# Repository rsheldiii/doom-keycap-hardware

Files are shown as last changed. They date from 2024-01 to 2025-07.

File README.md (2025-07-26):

# Doom Keycap Hardware Repository



Here are all the files associated with the hardware for the Doom Keycap. If you're looking for the code, it's [here](https://github.com/rsheldiii/rp2040-doom-LCD/).

I had every intention of fabricating and selling these myself, but I got caught up on how to manufacture the keycap itself without A. breaking the bank, or B. doing a group buy before realizing my design wasn't feasible. With that, coupled with (happy) life events, I decided to open-source the hardware now.

## Doom Business Card

I handed out quite a few of these during OpenSauce 2025! You can check the subfolder for the front paste file (which you can use to generate a highly-recommended stencil at osh stencils) and the BOM. Happy soldering and good luck!

## Doom Keycap Kicad

This directory houses the Kicad files for the final version of the Doom Keycap PCB. It was essentially a mashup of the RP2040 minimal pcb and Adafruit's schematic for the [MAX98357AETE breakout board](https://learn.adafruit.com/adafruit-max98357-i2s-class-d-mono-amp/downloads), with a semi-standard FPC connector for SPI displays and smaller parts. Quick facts:

* The footprint library did not make the jump to a new operating system, but the footprints are embedded in the PCB file; you can right-click "edit footprint", save-as, and then reassociate them in the schematic. Or you know, you could not.
* I used screens from [this](https://www.aliexpress.us/item/3256803794221438.html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) aliexpress listing, which have FPC connectors that look like [this](https://imgur.com/btXJBdo). No other FPC connector will work on this iteration of the board (obviously)
* Finding a small but powerful enough speaker was a challenge. The small screen versions of the keycap did not have a speaker installed due to size constraints.
* I calculated the value of the crystal oscillator's capacitors wrong; it starts up, but it requires an extra flag during program compilation to give the crystal more time to stabilize. It should work as-is, but optimizing those values would be ideal
* The hardware design / components selected might not be well-optimized, I'm a computer scientist by trade. I did my best though.
* The flash memory could definitely be smaller, but beware: not all memory chips are drop-in replacements. Similarly, the voltage regulator could have a much smaller footprint, I just couldn't find one at the time. If you do swap the regulator and you want to play doom on the keycap with a keyboard, remember the regulator will be supplying electricity to the keyboard, not the other way around. 

## Doom Keycap Case

Here are the final couple STLs I generated for the model, plus the fusion 360 file I used to generate them. 

* the f3d file should have comments in the parameters section about the size of the larger screen, if you wish to make the large version of the keycap.
* If you want to install a speaker on the small version, you'll need to increase the space available to the PCB
* These parts were printed on a resin printer in transparent resin, processed, and then hit with clear gloss lacquer. My plan was to switch to an acrylic insert for mass production.

## Fabrication tips

* Unless you are a god-tier solderer, you're not going to get away with hand-soldering these boards; you will need a stencil and a reflow oven or similar. OSHPark has a sister-service for cheap stencils, which is what I used.
* You _can_ get away with a single stencil for the top of the board and hand-soldering the bottom though. the only tricky part is the FPC connector, but with extra flux and dragging the tip, the solder should wick where it needs to go. 
* The LED on the board is keyed to blink at certain critical moments in the program; if you aren't getting _any_ blinking at all, it means the device is malfunctioning. If you get _some_ blinking that stops, you probably forgot to burn the wad file to memory - I can't tell you how many times I did this. A screen does not have to be installed for the program to run successfully.
* if you upload a program that runs fine, but is then forgotten, you need to set PICO_XOSC_STARTUP_DELAY_MULTIPLIER. The crystal isn't stabilizing fast enough, which is causing the RP2040 to give up on reading the flash chip
* Fitment on the case is very tight; try not to over-bend the FPC on the screen
* Power can be delivered through the USB connector, or through the pads on the bottom of the PCB (refer to schematic for polarity). The voltage regulator in the BOM has more than enough power to run a simple keyboard, though I would be careful with LED keyboards. 1S lipos should work as well. If you want to use another power source, there are very many voltage regulators in the SOT223 package

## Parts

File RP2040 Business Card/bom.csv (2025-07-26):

Designator | Footprint | Quantity | Value | LCSC Part # | MFR Part #
C1, C17, C4, C9 | 402 | 4 | 10u | C15525 | CL05A106MQ5NUNC
C10, C8 | 402 | 2 | 1u | C52923 | CL05A105KA5NQNC
C11, C14, C15, C16, C18, C19, C20, C21, C5, C6, C7 | 402 | 11 | 100n | C1525 | CL05B104KO5NNNC
C12, C13 | 402 | 2 | 220p | C1530 | 0402B221K500NT
C2, C3 | 402 | 2 | 27p | C1557 | 0402CG270J500NT
D1 | 603 | 1 | LED | C2290 | KT-0603W
D2, D3 | 805 | 2 | D_Schottky
J1 | GCT_USB4105-GF-A | 1 | USB_C_Receptacle_USB2.0 | C3020560 | USB4105-GF-A
J2 | PinSocket_1x16_P2.54mm_Vertical | 1 | Conn_01x16_Socket
J6 | USB_C_Receptacle_GCT_USB4135-GF-A_6P_TopMnt_Horizontal | 1 | USB_C_Receptacle_PowerOnly_6P | C5438410 | USB4135-GF-A
LS1 | CMS_131304_smt_tr | 1 | Speaker | C9900205221 | CMS-131304-SMT-TR
R1, R5, R8 | 402 | 3 | 1k | C11702 | 0402WGF1001TCE
R10, R11 | 402 | 2 | 5.1k | C25905 | 0402WGF5101TCE
R12, R2 | 402 | 2 | DNF
R13, R9 | 402 | 2 | 56k | C25796 | 0402WGF5602TCE
R3, R4 | 402 | 2 | 27 | C138021 | RC0402FR-0727RL
R6 | 402 | 1 | 100k | C25741 | 0402WGF1003TCE
R7 | 402 | 1 | 680k | C163456 | RC0402FR-07680KL
SW1 | PTS636_SL50_SMTR_LFS Tactile Switch | 1 | Conn_01x02 | C2801322 | PTS636 SL50 SMTR LFS
U1 | SOT-223-3_TabPin2 | 1 | NCP1117-3.3_SOT223 | C26537 | NCP1117ST33T3G
U2 | SOIC-8_5.23x5.23mm_P1.27mm | 1 | W25Q128JVS | C97521 | W25Q128JVSIQ
U3 | RP2040-QFN-56 | 1 | RP2040 | C2040 | RP2040
U4 | 2328702-8 | 1 |  | C3168593 | 2328702-8
U5 | MAX98357AETE-T | 1 | MAX98357AETE+T | C910544 | MAX98357AETE+T
Y1 | 403C35D12M00000 | 1 | ABLS-12.000MHZ-B4-T | C1985831 | 403C35D12M00000

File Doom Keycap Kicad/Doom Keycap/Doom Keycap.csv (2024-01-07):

Source: | C:\Users\Dday\Documents\Documents\Projects\Doom Keycap\Doom Keycap Kicad\Doom Keycap\Doom Keycap.kicad_sch
Date: | 5/19/2023 12:42:28 PM
Tool: | Eeschema (6.0.9)
Generator: | C:\Program Files\KiCad\6.0\bin\scripting\plugins/bom_csv_grouped_by_value.py
Component Count: | 41
Individual Components:
Item | Qty | Reference(s) | Value | LibPart | Footprint | Datasheet
 |  | C1 | 10u | Device:C | Capacitor_SMD:C_0402_1005Metric | ~
 |  | C2 | 27p | Device:C | Capacitor_SMD:C_0402_1005Metric | ~
 |  | C3 | 27p | Device:C | Capacitor_SMD:C_0402_1005Metric | ~
 |  | C4 | 10u | Device:C | Capacitor_SMD:C_0402_1005Metric | ~
 |  | C5 | 100n | Device:C | Capacitor_SMD:C_0402_1005Metric | ~
 |  | C6 | 100n | Device:C | Capacitor_SMD:C_0402_1005Metric | ~
 |  | C7 | 100n | Device:C | Capacitor_SMD:C_0402_1005Metric | ~
 |  | C8 | 1u | Device:C | Capacitor_SMD:C_0402_1005Metric | ~
 |  | C9 | 10u | Device:C | Capacitor_SMD:C_0402_1005Metric | ~
 |  | C10 | 1u | Device:C | Capacitor_SMD:C_0402_1005Metric | ~
 |  | C11 | 100n | Device:C | Capacitor_SMD:C_0402_1005Metric | ~
 |  | C12 | 220p | Device:C | Capacitor_SMD:C_0402_1005Metric | ~
 |  | C13 | 220p | Device:C | Capacitor_SMD:C_0402_1005Metric | ~
 |  | C17 | 10u | Device:C | Capacitor_SMD:C_0402_1005Metric | ~
 |  | D1 | LED | Device:LED | LED_SMD:LED_0603_1608Metric | ~
 |  | D2 | D_Schottky | Device:D_Schottky | Diode_SMD:D_0402_1005Metric | ~
 |  | FID1 | Fiducial | Mechanical:Fiducial | Fiducial:Fiducial_0.5mm_Mask1mm | ~
 |  | FID2 | Fiducial | Mechanical:Fiducial | Fiducial:Fiducial_0.5mm_Mask1mm | ~
 |  | FID3 | Fiducial | Mechanical:Fiducial | Fiducial:Fiducial_0.5mm_Mask1mm | ~
 |  | FID4 | Fiducial | Mechanical:Fiducial | Fiducial:Fiducial_0.5mm_Mask1mm | ~
 |  | FID5 | Fiducial | Mechanical:Fiducial | Fiducial:Fiducial_0.5mm_Mask1mm | ~
 |  | FID6 | Fiducial | Mechanical:Fiducial | Fiducial:Fiducial_0.5mm_Mask1mm | ~
 |  | J1 | USB_B_Micro | Doom-Keycap-rescue:USB_B_Micro-Connector | RP2040_minimal:USB_Micro-B_Amphenol_10103594-0001LF_Horizontal_modified
 |  | J2 | Conn_01x02 | Jumper:SolderJumper_2_Open | Jumper:SolderJumper-2_P1.3mm_Open_Pad1.0x1.5mm | ~
 |  | J3 | Conn_01x01_Female | Connector:Conn_01x01_Female | TestPoint:TestPoint_Pad_D1.0mm | ~
 |  | J4 | Conn_01x01_Female | Connector:Conn_01x01_Female | TestPoint:TestPoint_Pad_D1.0mm | ~
 |  | LS1 | Speaker | Device:Speaker | Custom:SMS-1308MS-2-R | ~
 |  | R1 | 1k | Device:R | Resistor_SMD:R_0402_1005Metric | ~
 |  | R2 | DNF | Device:R | Resistor_SMD:R_0402_1005Metric | ~
 |  | R3 | 27 | Device:R | Resistor_SMD:R_0402_1005Metric | ~
 |  | R4 | 27 | Device:R | Resistor_SMD:R_0402_1005Metric | ~
 |  | R5 | 1k | Device:R | Resistor_SMD:R_0402_1005Metric | ~
 |  | R6 | 100k | Device:R | Resistor_SMD:R_0402_1005Metric | ~
 |  | R7 | 680k | Device:R | Resistor_SMD:R_0402_1005Metric | ~
 |  | R8 | 1K | Device:R | Resistor_SMD:R_0402_1005Metric | ~
 |  | U1 | NCP1117-3.3_SOT223 | Regulator_Linear:NCP1117-3.3_SOT223 | Package_TO_SOT_SMD:SOT-223-3_TabPin2 | http://www.onsemi.com/pub_link/Collateral/NCP1117-D.PDF
 |  | U2 | W25Q128JVS | Memory_Flash:W25Q128JVS | Package_SO:SOIC-8_5.23x5.23mm_P1.27mm | http://www.winbond.com/resource-files/w25q128jv_dtr%20revc%2003272018%20plus.pdf
 |  | U3 | RP2040 | MCU_RaspberryPi_RP2040:RP2040 | RP2040_minimal:RP2040-QFN-56
 |  | U4 | ST7735s_8 | Custom:ST7735s_8 | Custom:2328702-8
 |  | U5 | MAX98357AETE+T | Amp:MAX98357AETE+T | Custom:MAX98357AETE-T
 |  | Y1 | ABLS-12.000MHZ-B4-T | Device:Crystal | Custom:403C35D12M00000 | ~
Collated Components:
Item | Qty | Reference(s) | Value | LibPart | Footprint | Datasheet
1 | 4 | C1, C4, C9, C17 | 10u | Device:C | Capacitor_SMD:C_0402_1005Metric | ~
2 | 2 | C2, C3 | 27p | Device:C | Capacitor_SMD:C_0402_1005Metric | ~
3 | 4 | C5, C6, C7, C11 | 100n | Device:C | Capacitor_SMD:C_0402_1005Metric | ~
4 | 2 | C8, C10 | 1u | Device:C | Capacitor_SMD:C_0402_1005Metric | ~
5 | 2 | C12, C13 | 220p | Device:C | Capacitor_SMD:C_0402_1005Metric | ~
6 | 1 | D1 | LED | Device:LED | LED_SMD:LED_0603_1608Metric | ~
7 | 1 | D2 | D_Schottky | Device:D_Schottky | Diode_SMD:D_0402_1005Metric | ~
8 | 6 | FID1, FID2, FID3, FID4, FID5, FID6 | Fiducial | Mechanical:Fiducial | Fiducial:Fiducial_0.5mm_Mask1mm | ~
9 | 1 | J1 | USB_B_Micro | Doom-Keycap-rescue:USB_B_Micro-Connector | RP2040_minimal:USB_Micro-B_Amphenol_10103594-0001LF_Horizontal_modified
10 | 1 | J2 | Conn_01x02 | Jumper:SolderJumper_2_Open | Jumper:SolderJumper-2_P1.3mm_Open_Pad1.0x1.5mm | ~
11 | 2 | J3, J4 | Conn_01x01_Female | Connector:Conn_01x01_Female | TestPoint:TestPoint_Pad_D1.0mm | ~
12 | 1 | LS1 | Speaker | Device:Speaker | Custom:SMS-1308MS-2-R | ~
13 | 2 | R1, R5 | 1k | Device:R | Resistor_SMD:R_0402_1005Metric | ~
14 | 1 | R2 | DNF | Device:R | Resistor_SMD:R_0402_1005Metric | ~
15 | 2 | R3, R4 | 27 | Device:R | Resistor_SMD:R_0402_1005Metric | ~
16 | 1 | R6 | 100k | Device:R | Resistor_SMD:R_0402_1005Metric | ~
17 | 1 | R7 | 680k | Device:R | Resistor_SMD:R_0402_1005Metric | ~
18 | 1 | R8 | 1K | Device:R | Resistor_SMD:R_0402_1005Metric | ~
19 | 1 | U1 | NCP1117-3.3_SOT223 | Regulator_Linear:NCP1117-3.3_SOT223 | Package_TO_SOT_SMD:SOT-223-3_TabPin2 | http://www.onsemi.com/pub_link/Collateral/NCP1117-D.PDF
20 | 1 | U2 | W25Q128JVS | Memory_Flash:W25Q128JVS | Package_SO:SOIC-8_5.23x5.23mm_P1.27mm | http://www.winbond.com/resource-files/w25q128jv_dtr%20revc%2003272018%20plus.pdf
21 | 1 | U3 | RP2040 | MCU_RaspberryPi_RP2040:RP2040 | RP2040_minimal:RP2040-QFN-56
22 | 1 | U4 | ST7735s_8 | Custom:ST7735s_8 | Custom:2328702-8
23 | 1 | U5 | MAX98357AETE+T | Amp:MAX98357AETE+T | Custom:MAX98357AETE-T
24 | 1 | Y1 | ABLS-12.000MHZ-B4-T | Device:Crystal | Custom:403C35D12M00000 | ~

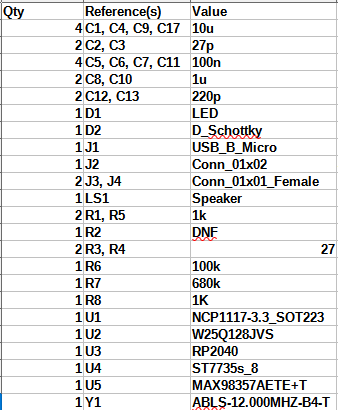
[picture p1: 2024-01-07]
bom.png

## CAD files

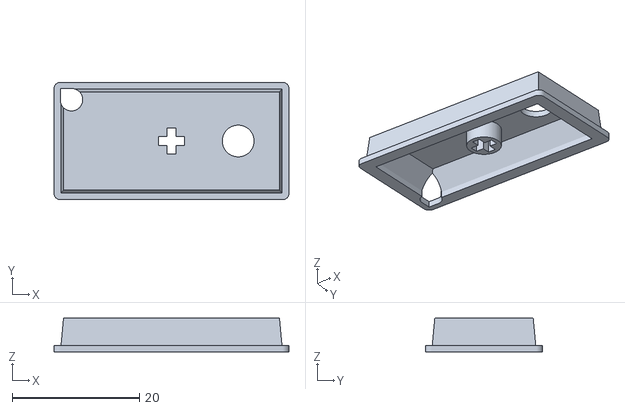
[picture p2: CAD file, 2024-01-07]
Doom Keycap Case/SuperSlammed - Small Screen - Covered - 4deg tilt - Inner.stl
37.0 x 18.5 x 5.30

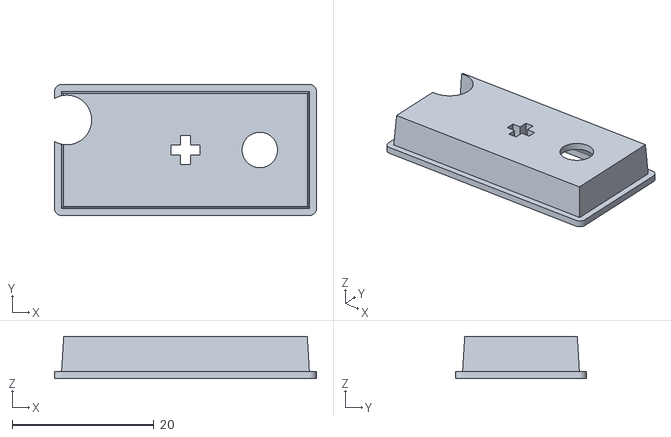
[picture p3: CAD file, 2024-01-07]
Doom Keycap Case/SuperSlammed-SmallScreen-Inner-ChunkRemoved.stl
37.0 x 18.5 x 6.00

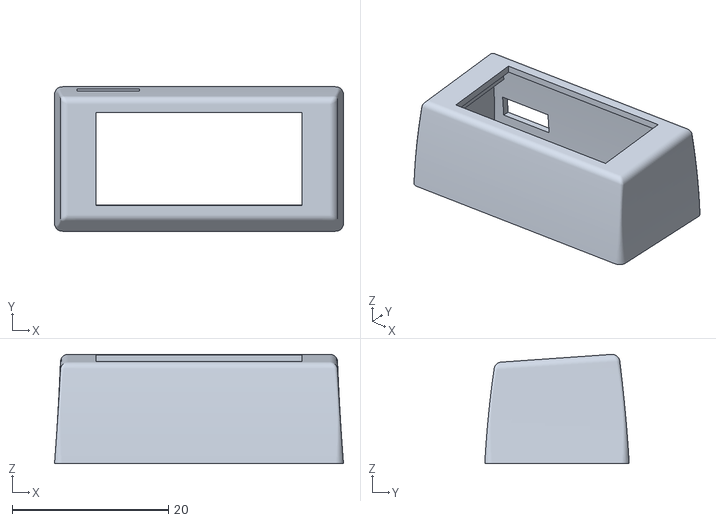
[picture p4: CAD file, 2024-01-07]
Doom Keycap Case/SuperSlammed - Small Screen - 4deg tilt - open - outer.stl
37.0 x 18.5 x 14.0

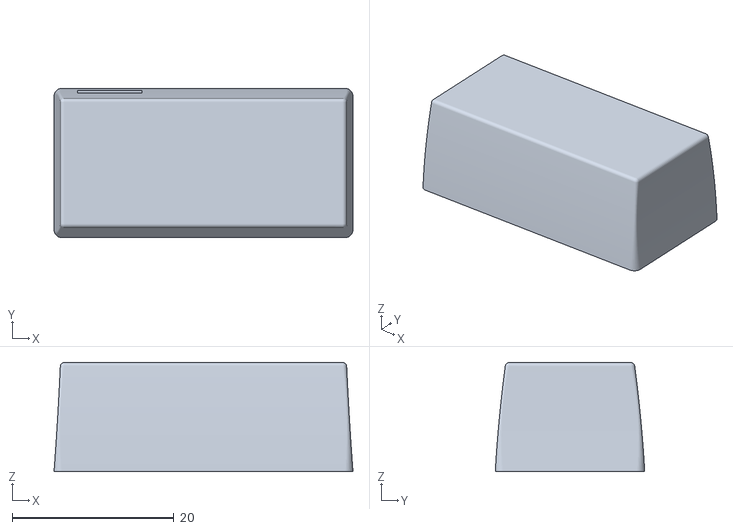
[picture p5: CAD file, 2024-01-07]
Doom Keycap Case/SuperSlammed - Small Screen - Closed - Outer.stl
37.0 x 18.5 x 13.5

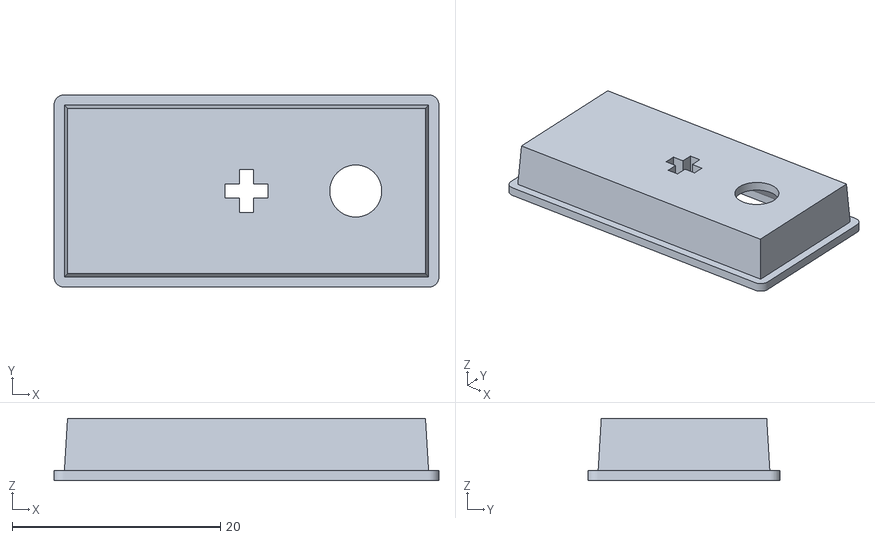
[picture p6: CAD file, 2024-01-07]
Doom Keycap Case/SuperSlammed-SmallScreen-inner.stl
37.0 x 18.5 x 6.00

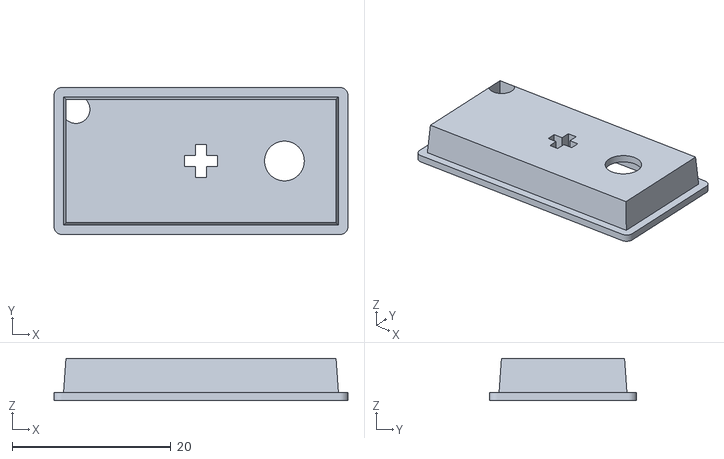
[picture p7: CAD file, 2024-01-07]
Doom Keycap Case/Super Slammed - Small Screen - Closed - Inner.stl
37.0 x 18.5 x 5.30

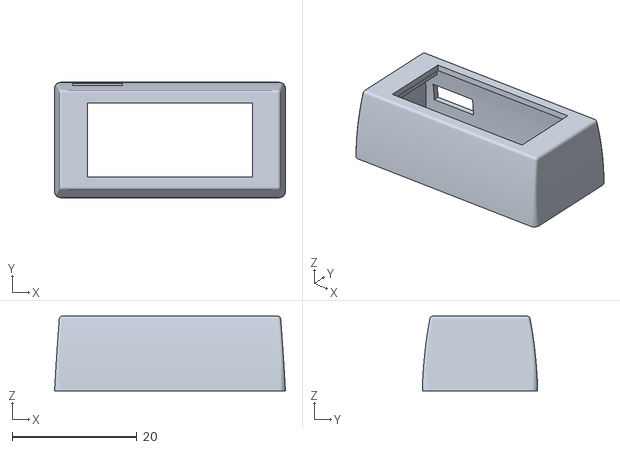
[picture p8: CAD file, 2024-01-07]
Doom Keycap Case/SuperSlammed-SmallScreen-outer.stl
37.0 x 18.5 x 12.0

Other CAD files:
Doom Keycap Case/SuperSlammed - Small Screen - Covered - Inner.stl
Doom Keycap Case/SuperSlammed - Small Screen - Covered - 4deg tilt - outer.stl
Doom Keycap Case/Doom Keycap Prototype Enclosure v22.f3d

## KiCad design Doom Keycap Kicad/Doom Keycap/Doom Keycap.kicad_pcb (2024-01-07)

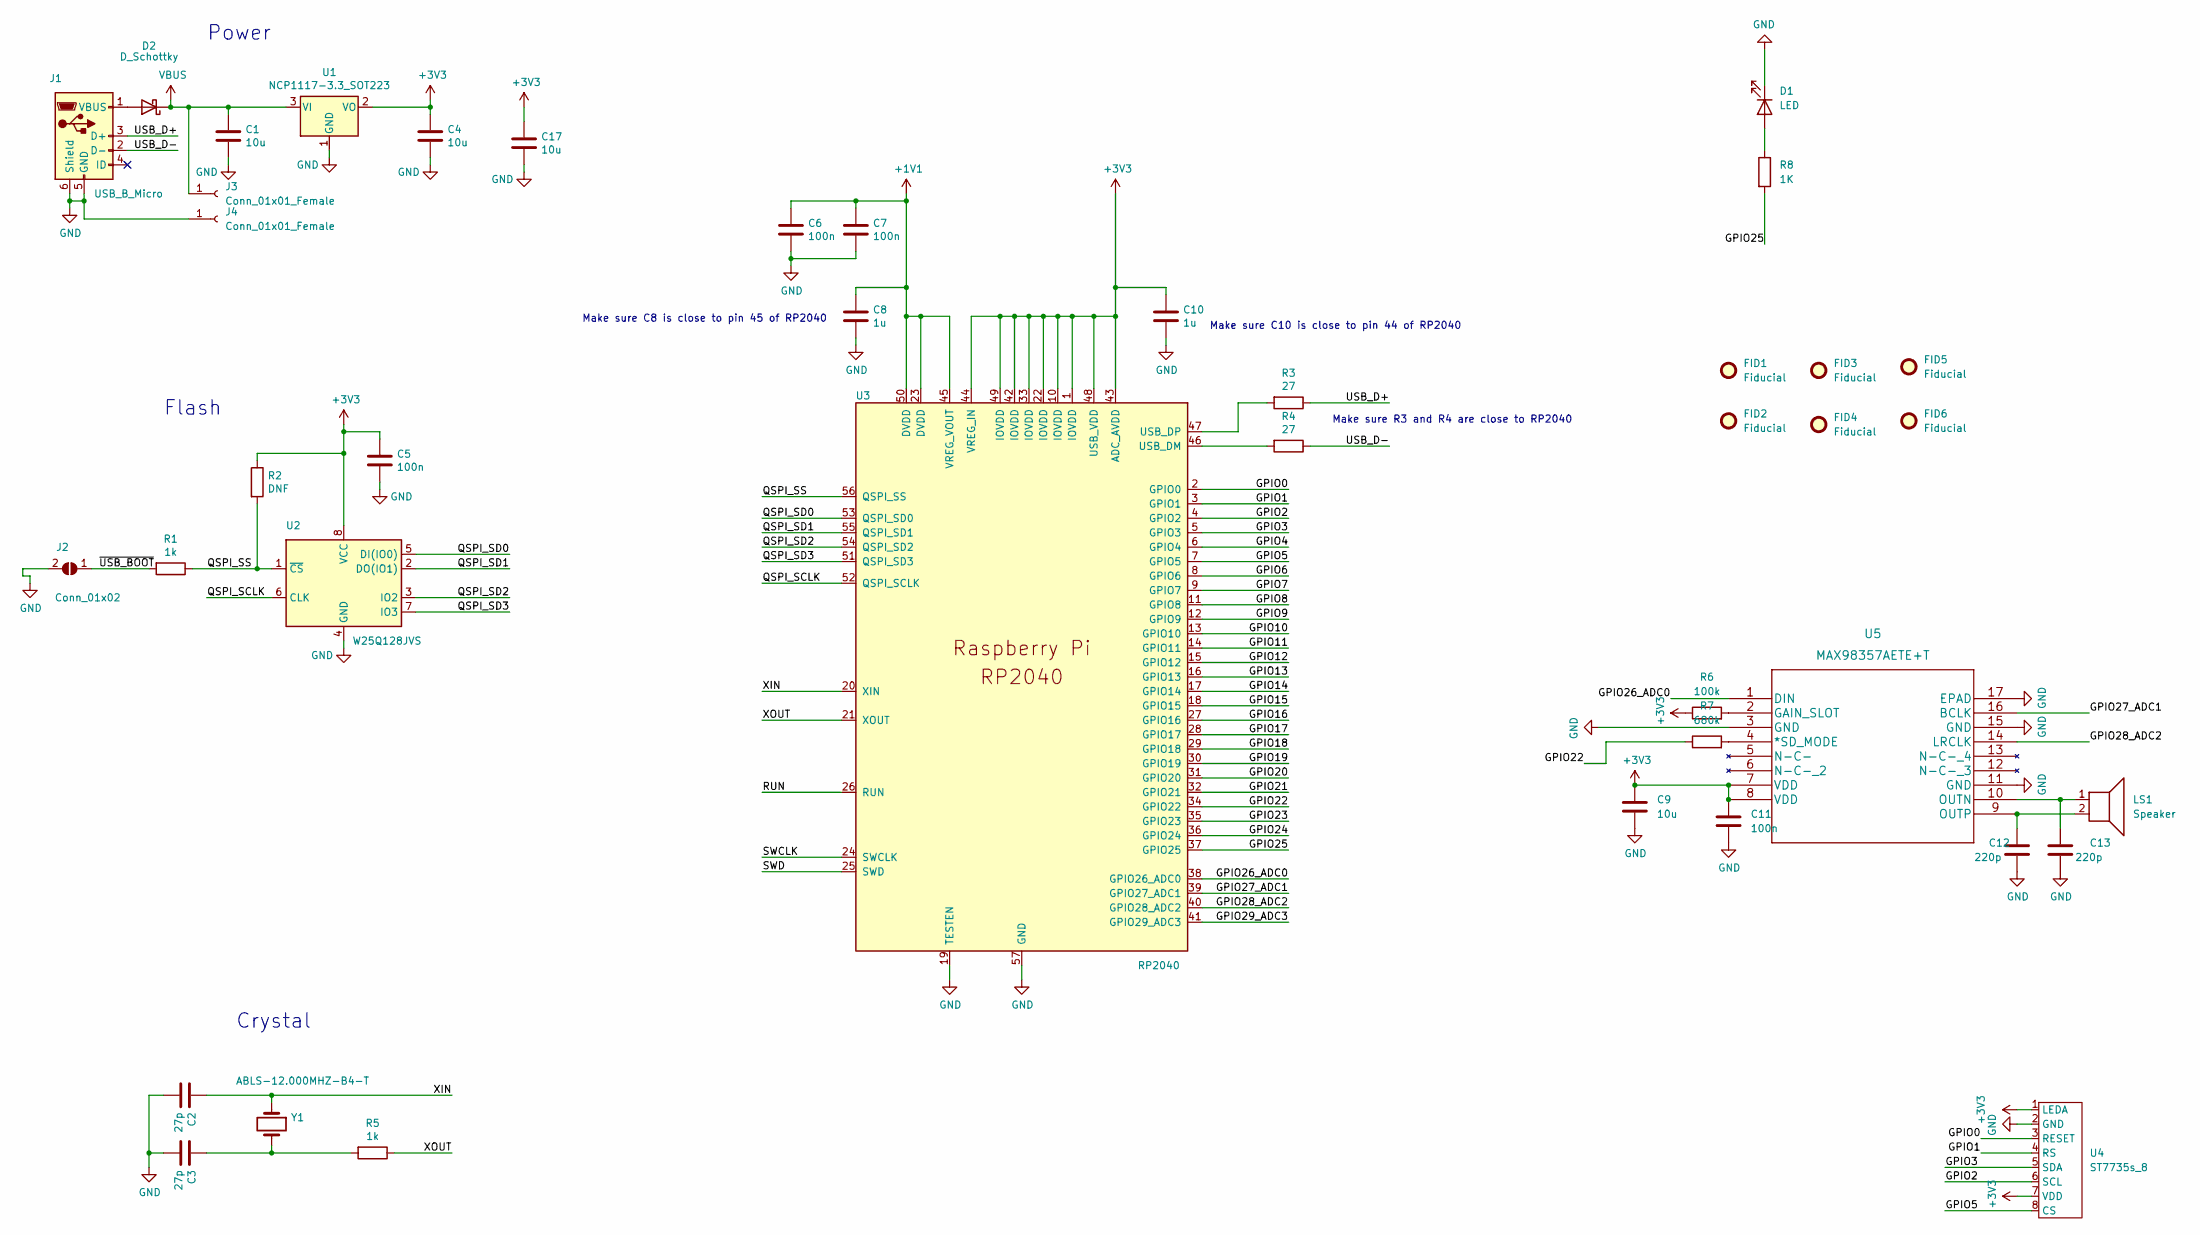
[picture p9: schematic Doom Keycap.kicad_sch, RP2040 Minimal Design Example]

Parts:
C1, C4, C9, C17: 10u; C_0402_1005Metric
C2, C3: 27p; C_0402_1005Metric
C5, C6, C7, C11: 100n; C_0402_1005Metric
C8, C10: 1u; C_0402_1005Metric
C12, C13: 220p; C_0402_1005Metric
D1: LED; LED_0603_1608Metric
D2: D_Schottky; D_0402_1005Metric
FID1, FID2, FID3, FID4, FID5, FID6: Fiducial; Fiducial_0.5mm_Mask1mm
J1: USB_B_Micro; USB_Micro-B_Amphenol_10103594-0001LF_Horizontal_modified
J2: Conn_01x02; SolderJumper-2_P1.3mm_Open_Pad1.0x1.5mm
J3, J4: Conn_01x01_Female; TestPoint_Pad_D1.0mm
LS1: Speaker; SMS-1308MS-2-R
R1, R5: 1k; R_0402_1005Metric
R2: DNF; R_0402_1005Metric
R3, R4: 27; R_0402_1005Metric
R6: 100k; R_0402_1005Metric
R7: 680k; R_0402_1005Metric
R8: 1K; R_0402_1005Metric
U1: NCP1117-3.3_SOT223; SOT-223-3_TabPin2
U2: W25Q128JVS; SOIC-8_5.23x5.23mm_P1.27mm
U3: RP2040; RP2040-QFN-56
U4: ST7735s_8; 2328702-8
U5: MAX98357AETE+T; MAX98357AETE-T
Y1: ABLS-12.000MHZ-B4-T; 403C35D12M00000

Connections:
+1V1: C6.1, C7.1, C8.1, U3.23 (DVDD), U3.45 (VREG_VOUT), U3.50 (DVDD)
+3V3: C4.1, C5.1, C9.1, C10.1, C11.1, C17.1, R2.1, R6.1, U1.2 (VO), U2.8 (VCC), U3.1 (IOVDD), U3.10 (IOVDD), U3.22 (IOVDD), U3.33 (IOVDD), U3.42 (IOVDD), U3.43 (ADC_AVDD), U3.44 (VREG_IN), U3.48 (USB_VDD), U3.49 (IOVDD), U4.1 (LEDA), U4.7 (VDD), U5.7 (VDD), U5.8 (VDD)
/GPIO0: U3.2 (GPIO0), U4.3 (RESET)
/GPIO1: U3.3 (GPIO1), U4.4 (RS)
/GPIO2: U3.4 (GPIO2), U4.6 (SCL)
/GPIO3: U3.5 (GPIO3), U4.5 (SDA)
/GPIO4: U3.6 (GPIO4)
/GPIO5: U3.7 (GPIO5), U4.8 (CS)
/GPIO6: U3.8 (GPIO6)
/GPIO7: U3.9 (GPIO7)
/GPIO8: U3.11 (GPIO8)
/GPIO9: U3.12 (GPIO9)
/GPIO10: U3.13 (GPIO10)
/GPIO11: U3.14 (GPIO11)
/GPIO12: U3.15 (GPIO12)
/GPIO13: U3.16 (GPIO13)
/GPIO14: U3.17 (GPIO14)
/GPIO15: U3.18 (GPIO15)
/GPIO16: U3.27 (GPIO16)
/GPIO17: U3.28 (GPIO17)
/GPIO18: U3.29 (GPIO18)
/GPIO19: U3.30 (GPIO19)
/GPIO20: U3.31 (GPIO20)
/GPIO21: U3.32 (GPIO21)
/GPIO22: R7.1, U3.34 (GPIO22)
/GPIO23: U3.35 (GPIO23)
/GPIO24: U3.36 (GPIO24)
/GPIO25: R8.2, U3.37 (GPIO25)
/GPIO26_ADC0: U3.38 (GPIO26_ADC0), U5.1 (DIN)
/GPIO27_ADC1: U3.39 (GPIO27_ADC1), U5.16 (BCLK)
/GPIO28_ADC2: U3.40 (GPIO28_ADC2), U5.14 (LRCLK)
/GPIO29_ADC3: U3.41 (GPIO29_ADC3)
/QSPI_SCLK: U2.6 (CLK), U3.52 (QSPI_SCLK)
/QSPI_SD0: U2.5 (DI(IO0)), U3.53 (QSPI_SD0)
/QSPI_SD1: U2.2 (DO(IO1)), U3.55 (QSPI_SD1)
/QSPI_SD2: U2.3 (IO2), U3.54 (QSPI_SD2)
/QSPI_SD3: U2.7 (IO3), U3.51 (QSPI_SD3)
/QSPI_SS: R1.1, R2.2, U2.1 (~CS), U3.56 (QSPI_SS)
/RUN: U3.26 (RUN)
/SWCLK: U3.24 (SWCLK)
/SWD: U3.25 (SWD)
/USB_D+: J1.3 (D+), R3.1
/USB_D-: J1.2 (D-), R4.1
/XIN: C2.1, U3.20 (XIN), Y1.1
/XOUT: R5.1, U3.21 (XOUT)
/~USB_BOOT: J2.1 (A), R1.2
GND: C1.2, C2.2, C3.2, C4.2, C5.2, C6.2, C7.2, C8.2, C9.2, C10.2, C11.2, C12.2, C13.2, C17.2, D1.1 (K), J1.5 (GND), J1.6 (Shield), J2.2 (B), J4.1, U1.1 (GND), U2.4 (GND), U3.19 (TESTEN), U3.57 (GND), U4.2 (GND), U5.3 (GND), U5.11 (GND), U5.15 (GND), U5.17 (EPAD)
unnamed: C3.1, R5.2, Y1.2
unnamed: C12.1, LS1.2, U5.9 (OUTP)
unnamed: C13.1, LS1.1, U5.10 (OUTN)
unnamed: D1.2 (A), R8.1
unnamed: D2.2 (A), J1.1 (VBUS)
unnamed: R3.2, U3.47 (USB_DP)
unnamed: R4.2, U3.46 (USB_DM)
unnamed: R6.2, U5.2 (GAIN_SLOT)
unnamed: R7.2, U5.4 (*SD_MODE)
VBUS: C1.1, D2.1 (K), J3.1, U1.3 (VI)

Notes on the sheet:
Make sure C8 is close to pin 45 of RP2040
Make sure C10 is close to pin 44 of RP2040
Make sure R3 and R4 are close to RP2040
Flash
Crystal
Power

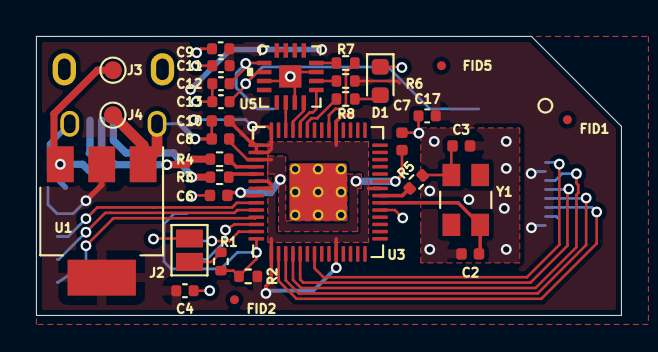
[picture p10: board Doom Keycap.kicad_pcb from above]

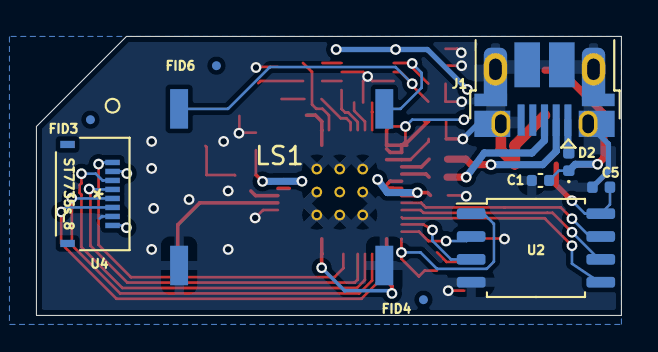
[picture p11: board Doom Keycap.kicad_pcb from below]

Board: 2 copper layers, 32.5 x 15.5 mm, 41 parts (10 on the bottom side), 34 nets.

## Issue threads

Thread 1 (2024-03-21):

BOM and footprints wrong

olDirdey, 2024-03-21:
1) can´t find D2 on the PCB. Not needed?
2) C1 / C4 and C17 are 0603 size components and not 0402 like in your .csv document

rsheldiii, 2024-04-24:
My apologies, this is caused by older gerber files #2.

I've uploaded the correct gerber files, if you use those instead you won't find these issues. D2 is a schottky diode to prevent current entering the USB bus, so it can be omitted

Closed 2024-04-24.

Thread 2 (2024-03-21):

provided Gerber files are older than the project

olDirdey, 2024-03-21:
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

zipplet, 2024-03-21:
Confirmed in Kicad, the pregenerated Gerber files in the JLCPCB folder are **incorrect**. The Kicad project is different. Please correct the pregenerated gerbers, people will order the wrong board.

Correct board layout from Kicad:

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

olDirdey, 2024-03-22:
> ...people will order the wrong board.

Sure, that's how the error was first noticed. Isn't even usable.

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

rsheldiii, 2024-04-24:
My apologies, I've updated the gerbers and they are now current to the kicad project.

I'm sorry @olDirdey. The pads are all there, but you won't be able to get video out of that board without some incredibly tricky soldering. You could still use the board as a test bed:

1. Verify you don't have any shorts in your soldering with a benchtop power supply. Reflow soldering is pretty tricky, I had several boards that just never worked
2. Verify USB posts by plugging into a computer - this is a half-step, it tells you that the RP2040 and some supporting components are functional
3. Verify flashing works - when everything is functioning properly, the LED will settle into a quick flash loop, indicating rendered frames. If the LED only comes on once, the firmware isn't being loaded at all or the crystal isn't synchronizing in time for the RP2040 to read from flash; if the LED comes on a few times, odds are the WAD file isn't burned / is misaligned.

Getting to that quick flash state indicates a working board which is no small feat. Again, sorry for the trouble.

Closed 2024-04-24.

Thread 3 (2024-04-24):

2 BOM available / wrong Footprints

olDirdey, 2024-04-24:
There are more errors. You have uploaded 2 different BOM (csv and png) which differ in the parts list. Then 2 footprints are wrong. D2 does not match the schematic and U5 does not match the silkscreen

olDirdey, 2024-04-24:
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
 I have built 2, both are recognized on the pc and both allow the firmware upload without any problems. but both only have a static LED afterwards and the screen only has a backlight. must first set up a pc with linux to view the serial console, have no access to it with win 7

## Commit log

2024-04-24 Fix gerbers
    [Doom Keycap-B_Cu.gbl, Doom Keycap-B_Mask.gbs, Doom Keycap-B_Paste.gbp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]
2025-07-26 add doom business card F_Paste layer
    [Doom Business Card-F_Paste.gtp]
2025-07-26 add BOM for business card and restructure
    [bom.csv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]

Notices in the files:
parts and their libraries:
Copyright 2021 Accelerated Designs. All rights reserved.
